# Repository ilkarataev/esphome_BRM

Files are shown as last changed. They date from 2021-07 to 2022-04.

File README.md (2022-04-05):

# esphome_Board_Relays_Modules  
В репозитории находятся файлы для создания плат. Платы управляют 8 и 4 стандатрными релейными модулями. Возможно скоро добавлю видео по использованию.
  
### 8 релейный модуль  
Gerber,BOM файл 8_relays_modules/gerber_file/  
Компоненты для распайки:  
Ссылки и стоимость в Челябинске с Али конечно будет дешевле.  
1.Hilink 220v->5. - 1штука [300р](https://procontact74.ru/22-zaryadnye-ustrojstva-bloki-pitaniya/221-impulsnye-bpi/ac-dc-preobrazovatel-220v---5v-06a-hi-link-hlk-pm01).  
2.Esp32 30 pins, на моей написанно devkitv1 - 1 штука [500р](https://procontact74.ru/14-arduino-elektronnye-moduli/222/bluetooth---wi-fi-modul-esp-32-devkit-v1-new).    
3.Стойка PCHSS-6 - 2штуки 5р\*2=[10р](https://procontact74.ru/ustanovochnye-izdeliya/stoyki-dlya-pp/stojka-pchss-6-05906) [14рЧипидип](https://www.chipdip.ru/catalog-show/pcb-metal-supports?gq=PCHSS-6)  
4.Стойка PCHSN-20 - 2штуки 12\*2=[24р](https://procontact74.ru/ustanovochnye-izdeliya/stoyki-dlya-pp/stoyka-pchsn-20)  
5.Клеммник KF301-2P или XY301V-A-2P синний - 1штука. [10р](https://procontact74.ru/27-kommutaciya/05-nakonechniki-klemmy/053-klemmniki-nazhimnye-razryvnye/xy301v-2p-5mm-05307)  
6.Клеммник XY301V-A-3P 5.08мм синий - 6 штук.6*12р=[72р](https://procontact74.ru/27-kommutaciya/05-nakonechniki-klemmy/053-klemmniki-nazhimnye-razryvnye/xy301v-3p-5mm-05308)  
7.Два болта m3.  
8.Резистор smd 0805 10K - 6 штук [6р](https://procontact74.ru/01-elektronnyie-komponentyi-/40-rezistory/407-chip-0805/10-kom-40750)  
9.Конденцатор 0805 4.7 nf 50V - 6штук [12р](https://procontact74.ru/01-elektronnyie-komponentyi-/41-kondensatory/416-smd/47-nf-41637)  
10.Header-Female-2.54_1x10 -1 штука (если найти сразу на длинной ноге то можно не надствалять).[10р](https://procontact74.ru/27-kommutaciya/02-razemy/razyemyi-bls%2C-bld%2C-pls%2C-pld/pbs-1x10-shag254-02006)  
11.Надствака для 10 позиции штыревой разъем 1x10 ряд 2,54. [10р](https://procontact74.ru/27-kommutaciya/02-razemy/razyemyi-bls%2C-bld%2C-pls%2C-pld/pls-40-tin-luzhenyj-02008) можно использовать от шилда [WEMOS](https://procontact74.ru/14-arduino-elektronnye-moduli/drayveryi-dvigateley%2C-shildyi/shild-dlya-wemos-d1-14232) отдельно такие разъемы я не нашел.  
12.Разъем 2.54мм PBS-1x16 (PBS-16) - 2ш(подключение есп32). [26р](https://procontact74.ru/27-kommutaciya/02-razemy/razyemyi-bls%2C-bld%2C-pls%2C-pld/razyem-2-54mm-pbs-1x16-%28pbs-16%29)  

[Реле 530р](https://procontact74.ru/14-arduino-elektronnye-moduli/releynyie-moduli/modul-rele-8-kanalov-14229) 

Итого компоненты без платы выходят 1500р.  
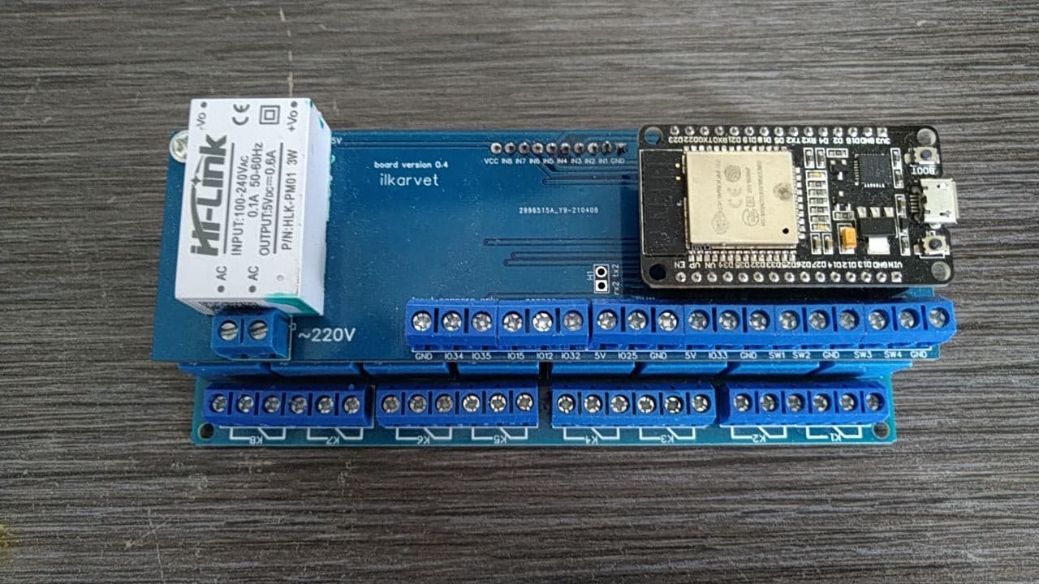
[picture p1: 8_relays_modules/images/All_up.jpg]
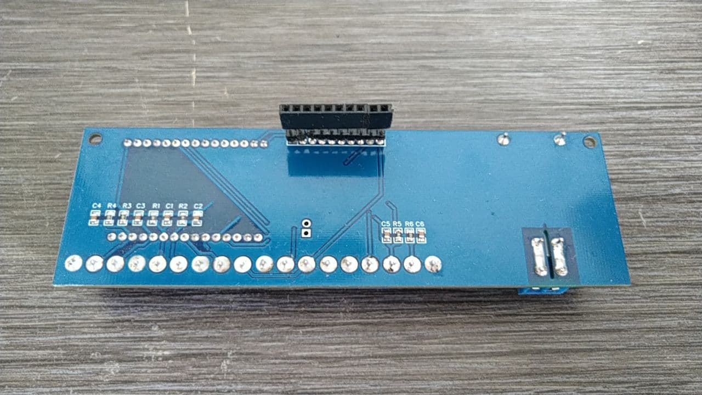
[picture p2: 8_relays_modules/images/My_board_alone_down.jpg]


Остальные фото в папке 8_relays_modules/images
### 4 релейный модуль  ВРЕМЕННО НЕ АКТУАЛЬНАЯ ИНФОРМАЦИЯ ТРЕБУЕТ ДОРАБОТКИ
Gerber,BOM файл 4_relays_modules/gerber_file/  
Корпус для печати на 3д принтере 4_relays_modules/box/
Компоненты для распайки:  
1.Hilink 220v->5. - 1штука [300р](https://procontact74.ru/22-zaryadnye-ustrojstva-bloki-pitaniya/221-impulsnye-bpi/ac-dc-preobrazovatel-220v---5v-06a-hi-link-hlk-pm01).   
2.Esp12F или Esp12e [у версии F лучше разведена антена](https://www.letscontrolit.com/wiki/index.php/Basics:_ESP8266_Types_and_Boards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,-%5BPic%5D%20%5BPinout&text=The%20only%20difference%20is%20the,pins%20lead%20to%20the%20outside.) - 1 штука [Esp12e-170р](https://procontact74.ru/14-arduino-elektronnye-moduli/222/wi-fi-modul-esp-12e-na-esp8266-14213) [Esp12F-195р](https://procontact74.ru/14-arduino-elektronnye-moduli/222/wi-fi-modul-esp-12f-na-esp8266-)    
3.Стойка PCHSS-6 - 2штуки 5р\*2=[10р](https://procontact74.ru/ustanovochnye-izdeliya/stoyki-dlya-pp/stojka-pchss-6-05906)  
4.Стойка PCHSN-20 - 2штуки 12\*2=[24р](https://procontact74.ru/ustanovochnye-izdeliya/stoyki-dlya-pp/stoyka-pchsn-20)  
5.Клеммник KF301-2P или XY301V-A-2P синний - 1штука. [10р](https://procontact74.ru/27-kommutaciya/05-nakonechniki-klemmy/)  
6.Клеммник XY301V-A-3P 5.08мм синий - 4 штук.4*12р=[48р](https://procontact74.ru/27-kommutaciya/05-nakonechniki-klemmy/053-klemmniki-nazhimnye-razryvnye/xy301v-3p-5mm-05308)   
7.Два болта m3.  
8.Резистор smd 0805 10K - 7 штук [7р](https://procontact74.ru/01-elektronnyie-komponentyi-/40-rezistory/407-chip-0805/10-kom-40750)   
9.Конденцатор 0805 4.7 nf 50V - 4 штуки [8р](https://procontact74.ru/01-elektronnyie-komponentyi-/41-kondensatory/416-smd/47-nf-41637)   
10.Header-Female-2.54_1x10 -1 штука (если найти сразу на длинной ноге то можно не надствалять).[10р](https://procontact74.ru/27-kommutaciya/02-razemy/razyemyi-bls%2C-bld%2C-pls%2C-pld/pbs-1x10-shag254-02006)  
11.Надствака для 10 позиции штыревой разъем 1x10 ряд 2,54. [10р](https://procontact74.ru/27-kommutaciya/02-razemy/razyemyi-bls%2C-bld%2C-pls%2C-pld/pls-40-tin-luzhenyj-02008) можно использовать от шилда [WEMOS](https://procontact74.ru/14-arduino-elektronnye-moduli/drayveryi-dvigateley%2C-shildyi/shild-dlya-wemos-d1-14232) отдельно такие разъемы я не нашел.   
12. Микросхема ams1117-3.3v [7р](https://procontact74.ru/01-elektronnyie-komponentyi-/45-mikroshemy/stabilizatoryi/ams1117-33-sot-223-450112)  
13. 74HC505A [10р на алиэкспреессе](https://aliexpress.ru/item/1005002345871977.html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)  
14. Конденцатор 0805 10uf - 1 штука [5р](https://procontact74.ru/01-elektronnyie-komponentyi-/41-kondensatory/416-smd/10-uf-41650)  
15. Конденцатор 0805 22uf - 1 штука [6р](https://procontact74.ru/01-elektronnyie-komponentyi-/41-kondensatory/416-smd/chip-0805-22-uf-10v-x5r-)  

[Реле 312р](https://procontact74.ru/14-arduino-elektronnye-moduli/releynyie-moduli/modul-rele-4-kanala-14078)  
Итого без платы 962р  

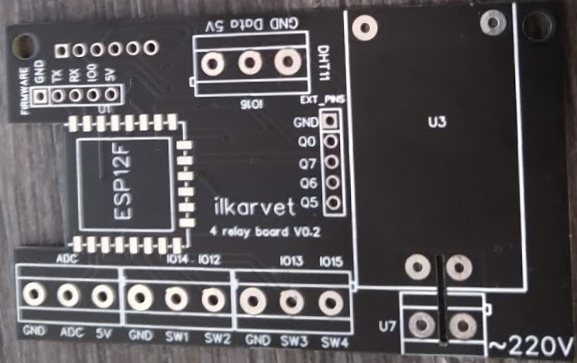
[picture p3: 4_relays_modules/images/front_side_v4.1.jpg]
front side
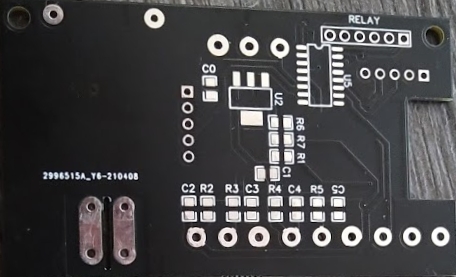
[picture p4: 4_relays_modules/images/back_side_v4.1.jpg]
back side


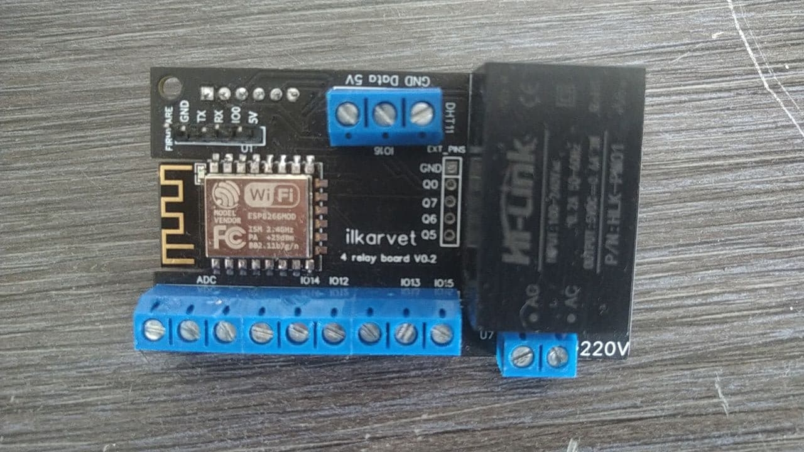
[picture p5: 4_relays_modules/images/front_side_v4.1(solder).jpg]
front side
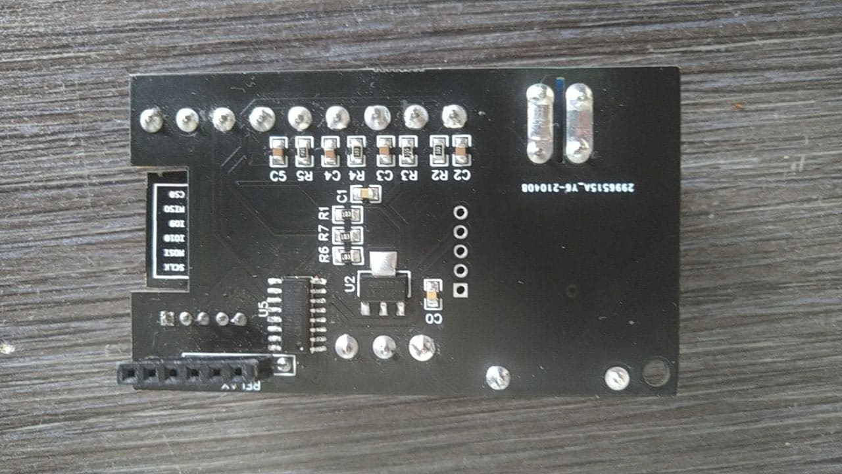
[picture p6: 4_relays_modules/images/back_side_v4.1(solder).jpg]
back side


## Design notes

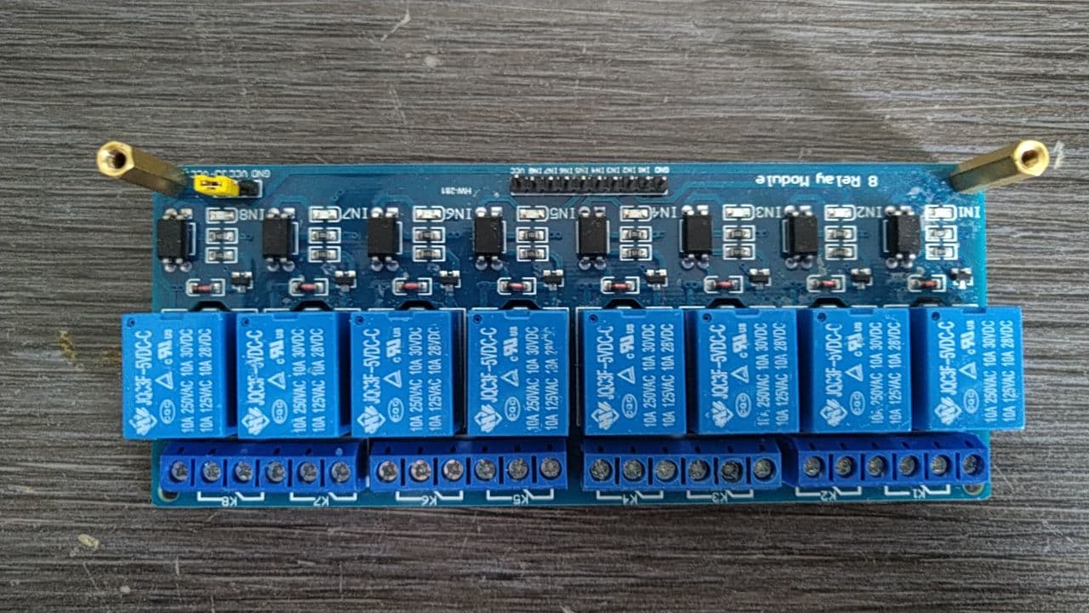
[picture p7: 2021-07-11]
8_relays_modules/images/8_relay_module.jpg

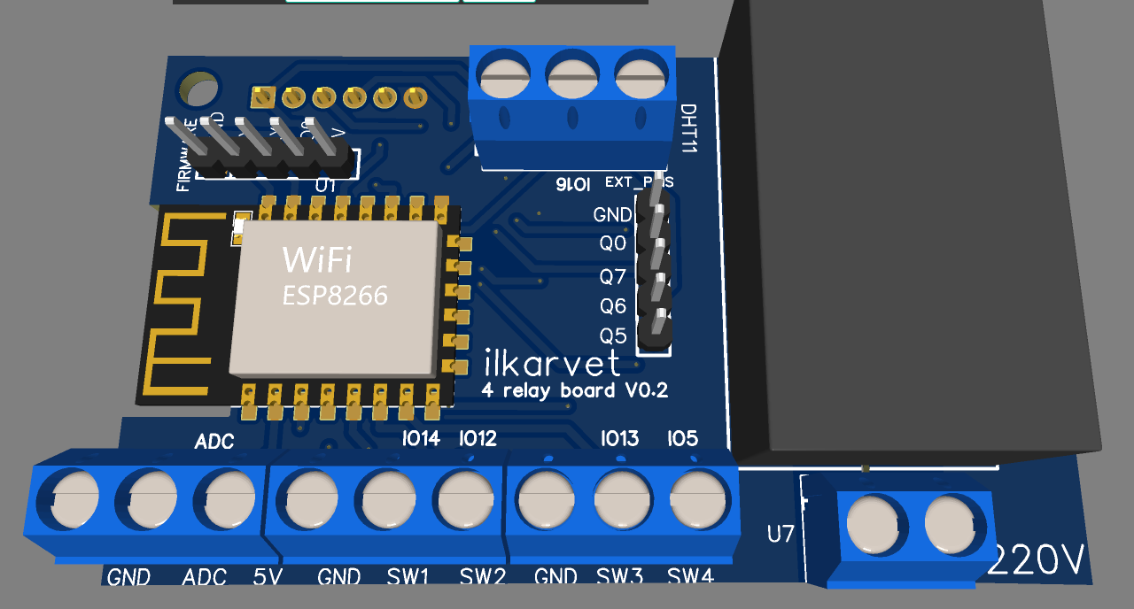
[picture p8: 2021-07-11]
4_relays_modules/images/3d_easyeda.png

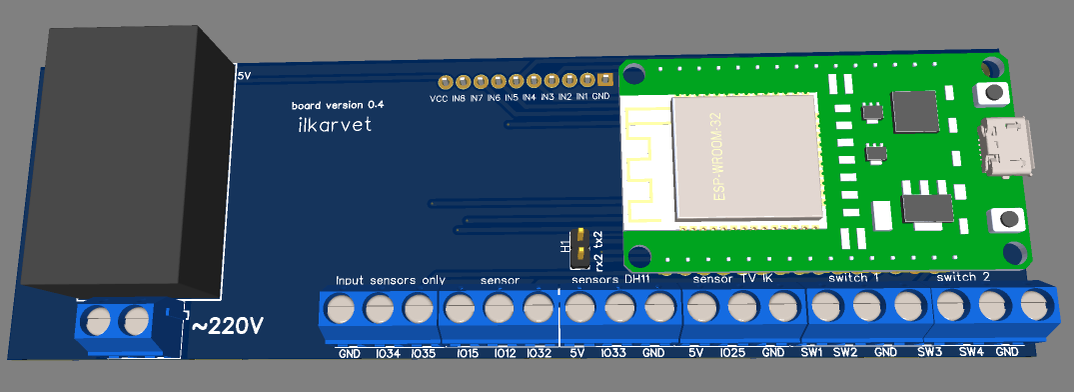
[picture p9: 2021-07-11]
8_relays_modules/images/3d.png

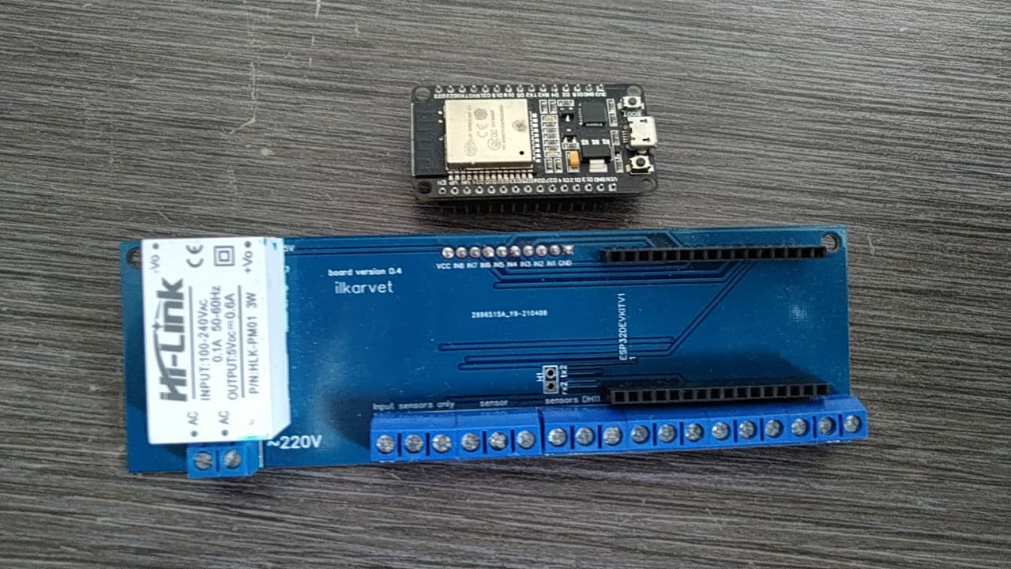
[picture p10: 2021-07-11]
8_relays_modules/images/My_board_alone_up.jpg

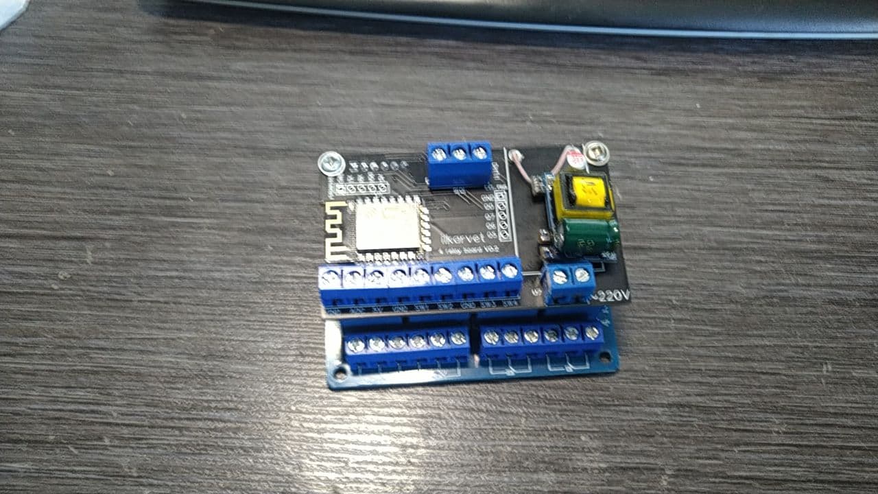
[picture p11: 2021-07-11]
4_relays_modules/images/All.jpg

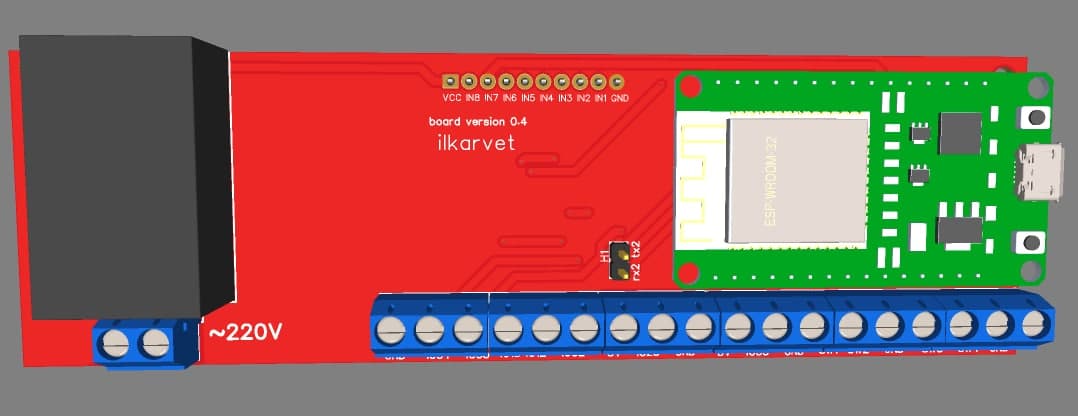
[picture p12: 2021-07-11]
8_relays_modules/images/easy_eda.jpg

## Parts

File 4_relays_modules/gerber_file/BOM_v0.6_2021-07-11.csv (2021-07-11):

ID | Name | Designator | Footprint | Quantity | Manufacturer Part | Manufacturer | Supplier | Supplier Part | Price
1 | AMS1117-3.3_C165482 | U2 | SOT-223_L6.5-W3.5-P2.30-LS7.0-BR | 1 | AMS1117-3.3 | SK | LCSC | C165482 | 0.0594
2 | Relay module 4 | RELAY | HDR-TH_6P-P2.54-V-F | 1 | Female header 1*6p | BOOMELE | LCSC | C40877 | 0.0684
3 | 10k | R3,R2,R4,R5,R6,R7 | 0805 | 6 | TC0525F1002T5E | UniOhm | LCSC | C57245 | 0.0097
4 | 10k | R1 | 0805 | 1 | TC0525F1002T5E | UniOhm | LCSC | C57245 | 0.0097
5 | 47nf | C2,C3,C5 | SENSORS-SMD_0805 | 3 | CL21B473KBCNNNC | SAMSUNG | LCSC | C53134 | 0.0109
6 | 22uf | C1 | SENSORS-SMD_0805 | 1 | CL21A226MQQNNNE | SAMSUNG | LCSC | C5674 | 0.0163
7 | 10uf | C0 | SENSORS-SMD_0805 | 1 | GRM21BR61C106KE15L | MuRata | LCSC | C77075 | 0.0187
8 | 47nf | C4 | SENSORS-SMD_0805 | 1 | CL21B473KBCNNNC | SAMSUNG | LCSC | C53134 | 0.0109
9 | 74HC595A | U5 | SOIC-16_L9.9-W3.9-P1.27-LS6.0-BL | 1 | 74HC595A | FM | LCSC | C110383 | 0.2259
10 | Header-Male-2.54_1x5 | EXT_PINS | HDR-TH_5P-P2.54-V-M | 1 | 210S-1*5P L=11.6MMGold-plated black | Ckmtw | LCSC | C124379 | 0.0378
11 | KF301-5.0-3P выключатель2 2Кнопки | U11 | CONN-TH_3P-P5.00_KF301-5.0-3P | 1 | KF301-5.0-3P | Cixi Kefa Elec | LCSC | C474882 | 0.1552
12 | KF301-5.0-3P выключатель 2 Кнопки | U9 | CONN-TH_3P-P5.00_KF301-5.0-3P | 1 | KF301-5.0-3P | Cixi Kefa Elec | LCSC | C474882 | 0.1552
13 | KF301-5.0-2P | U7 | CONN-TH_P5.00_KF301-5.0-2P | 1 | KF301-5.0-2P | Cixi Kefa Elec | LCSC | C474881 | 0.0918
14 | HLK-PM01 | U3 | PWRM-TH_HLK-PM01 | 1 | HLK-PM01 | HI-LINK | LCSC | C209903 | 3.7382
15 | ESP-12F(ESP8266MOD) | U1 | WIFIM-SMD_ESP-12F-ESP8266MOD | 1 | ESP-12F(ESP8266MOD) | Ai-Thinker | LCSC | C82891 | 1.5664
16 | Header-Male-2.54_1x5 | FIRMWARE | HDR-TH_5P-P2.54-V-M | 1 | 210S-1*5P L=11.6MMGold-plated black | Ckmtw | LCSC | C124379 | 0.0378
17 | KF301-5.0-3P DHT11 | DHT11 | CONN-TH_3P-P5.00_KF301-5.0-3P | 1 | KF301-5.0-3P | Cixi Kefa Elec | LCSC | C474882 | 0.1552
18 | KF301-5.0-3P | ADC | CONN-TH_3P-P5.00_KF301-5.0-3P | 1 | KF301-5.0-3P | Cixi Kefa Elec | LCSC | C474882 | 0.1552

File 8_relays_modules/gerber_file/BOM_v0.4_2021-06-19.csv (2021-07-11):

ID | Name | Designator | Footprint | Quantity | Manufacturer Part | Manufacturer | Supplier | Supplier Part | Price | LCSC Assembly | Paste Type
1 | ESP32DEVKITV1 | 1 | ESP32-DEVKIT-V1 | 1 |  |  | LCSC
2 | 47nf | C1,C2,C3,C4,C5,C6 | SENSORS-SMD_0805 | 6 | CL21B473KBCNNNC | SAMSUNG | LCSC | C53134 | 0.0115
3 | PZ254V-11-02P | H1 | HDR-TH_2P-P2.54-V-M | 1 | PZ254V-11-02P | XFCN | LCSC | C492401 | 0.0103 | Yes | expand
4 | Header-Female-2.54_1x10 | J1 | HDR-TH_10P-P2.54-V-F | 1 | 2.54mm 1*10P Straight Female header Gold-plated | BOOMELE | LCSC | C35445 | 0.0648
5 | 10k | R1,R2,R3,R4,R5,R6 | SENSORS-SMD_0805 | 6 | TC0525F1002T5E | UniOhm | LCSC | C57245 | 0.0097
6 | HLK-PM01 | U1 | PWRM-TH_HLK-PM01 | 1 | HLK-PM01 | HI-LINK | LCSC | C209903 | 3.7382 | Yes | expand
7 | KF301-5.0-2P | U2 | CONN-TH_P5.00_KF301-5.0-2P | 1 | KF301-5.0-2P | Cixi Kefa Elec | LCSC | C474881 | 0.0918
8 | switch 1 | U3 | CONN-TH_3P-P5.00_KF301-5.0-3P | 1 | KF301-5.0-3P | Cixi Kefa Elec | LCSC | C474882 | 0.1444
9 | switch 2 | U4 | CONN-TH_3P-P5.00_KF301-5.0-3P | 1 | KF301-5.0-3P | Cixi Kefa Elec | LCSC | C474882 | 0.1444
10 | sensors DH11 | U5 | CONN-TH_3P-P5.00_KF301-5.0-3P | 1 | KF301-5.0-3P | Cixi Kefa Elec | LCSC | C474882 | 0.1444
11 | sensor TV IK | U6 | CONN-TH_3P-P5.00_KF301-5.0-3P | 1 | KF301-5.0-3P | Cixi Kefa Elec | LCSC | C474882 | 0.1444
12 | sensor | U7,U8 | CONN-TH_3P-P5.00_KF301-5.0-3P | 2 | KF301-5.0-3P | Cixi Kefa Elec | LCSC | C474882 | 0.1444

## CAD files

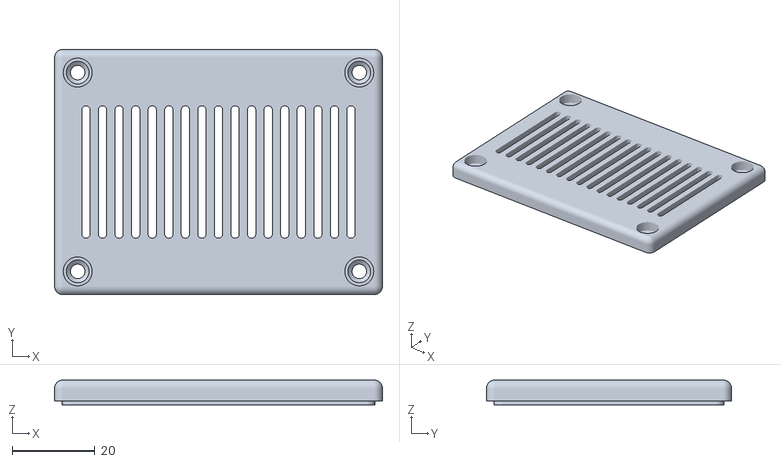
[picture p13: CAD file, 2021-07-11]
4_relays_modules/box/Крышка УД.STL
79.2 x 59.2 x 6.00

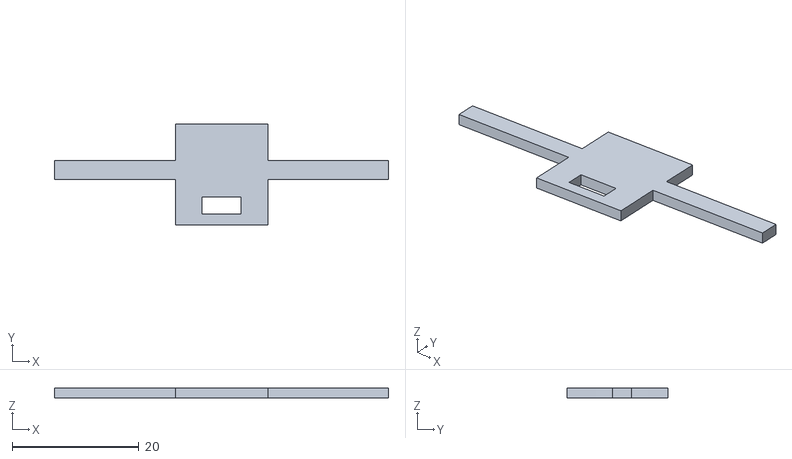
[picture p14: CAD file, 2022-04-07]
8_relays_modules/frame/din/замок 1.STL
52.6 x 15.9 x 1.60

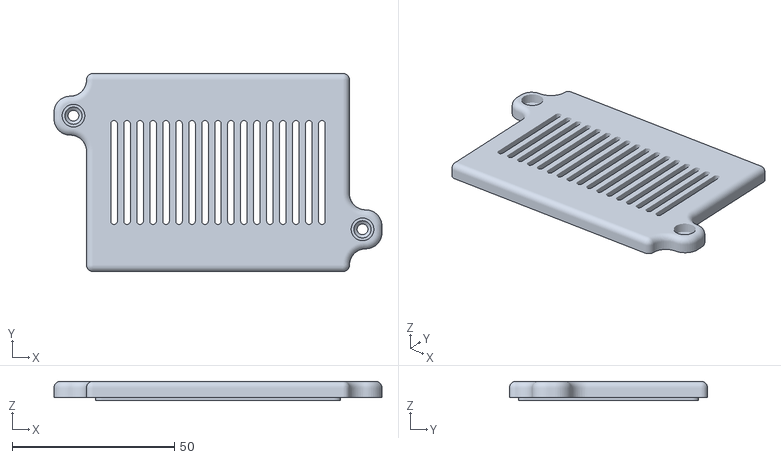
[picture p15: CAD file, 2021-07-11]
4_relays_modules/box/Крышка УД 1.STL
101.0 x 61.0 x 6.00

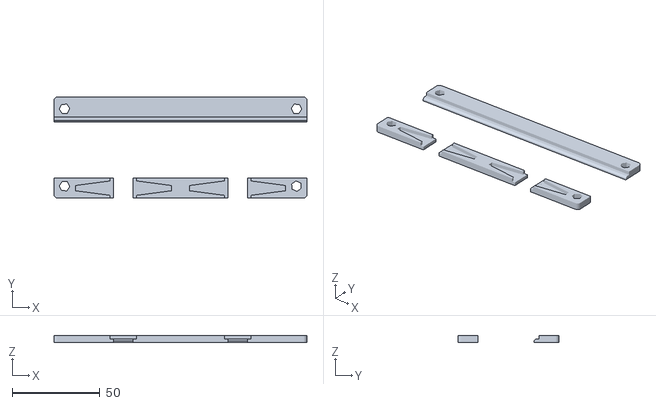
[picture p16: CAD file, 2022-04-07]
8_relays_modules/frame/din/корпус УД дно 2.STL
144.0 x 57.5 x 4.00

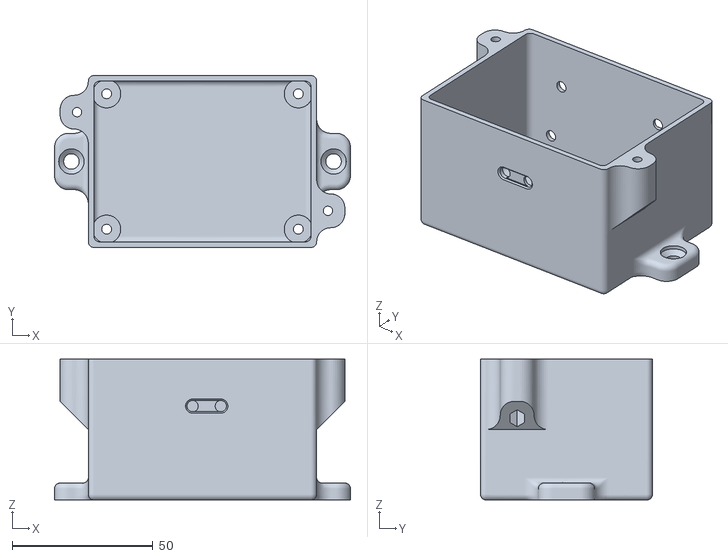
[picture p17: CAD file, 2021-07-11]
4_relays_modules/box/корпус УД 1.STL
105.0 x 61.0 x 50.0

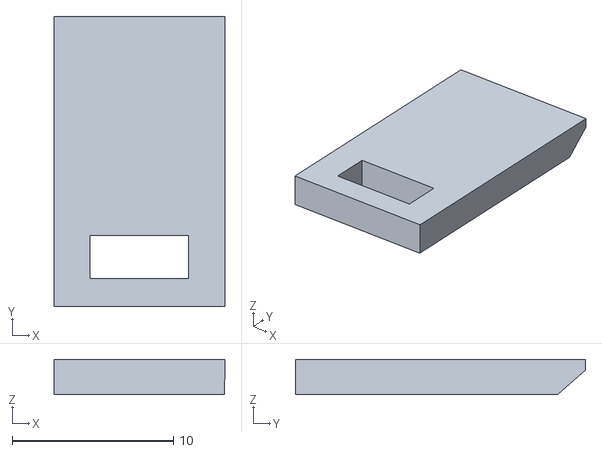
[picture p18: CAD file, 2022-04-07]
8_relays_modules/frame/din/замок 2.STL
10.6 x 18.0 x 2.20

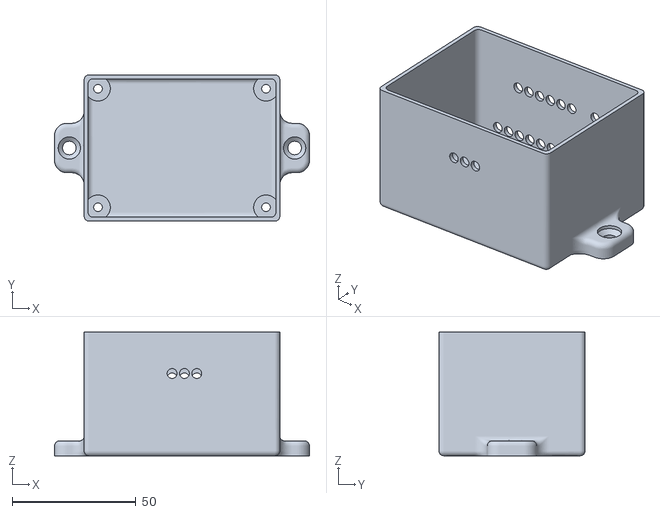
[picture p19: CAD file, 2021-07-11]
4_relays_modules/box/корпус УД.STL
103.2 x 59.2 x 50.0

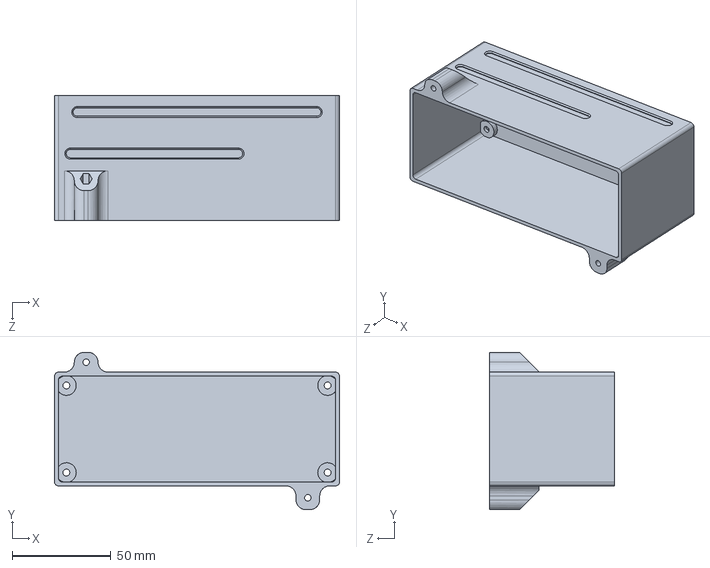
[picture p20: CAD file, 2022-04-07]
8_relays_modules/frame/din/корпус УД 2.SLDPRT
144.0 x 79.5 x 63.0 mm

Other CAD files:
8_relays_modules/frame/din/корпус УД 2.STL

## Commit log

2021-07-11 Добавил конфиг
2021-07-11 Добавил true конфиг
2022-04-07 Корпус на динрейку
    [замок 1.STL, замок 2.STL, корпус УД 2.SLDPRT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]
